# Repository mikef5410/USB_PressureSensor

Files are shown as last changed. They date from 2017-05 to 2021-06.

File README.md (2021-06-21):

## USB_Pressure_Sensor

USB measurement of Air pressure (compressor monitoring) The device also
includes an ambient air temperature, pressure, humidity monitor. As it happens
some of my work depends on a functioning air compressor, and ours is,
er... less than reliable. So, this device allows some of my automation to keep
an eye on the compressed air state, as well as air temperature, humidity and
pressure in the lab.

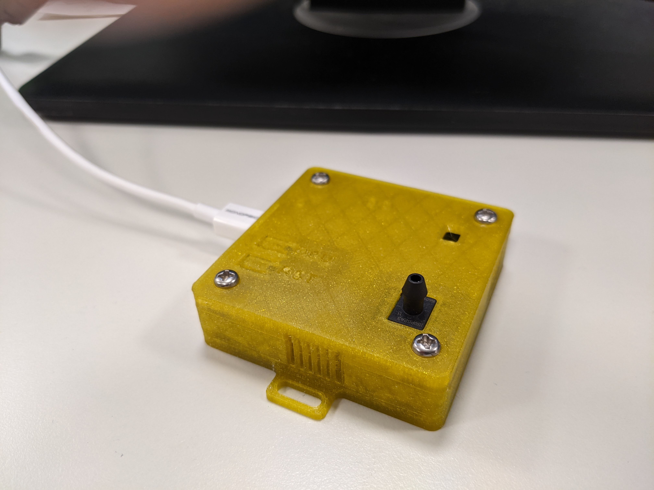
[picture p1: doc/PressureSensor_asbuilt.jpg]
USB Pressure Sensor as built


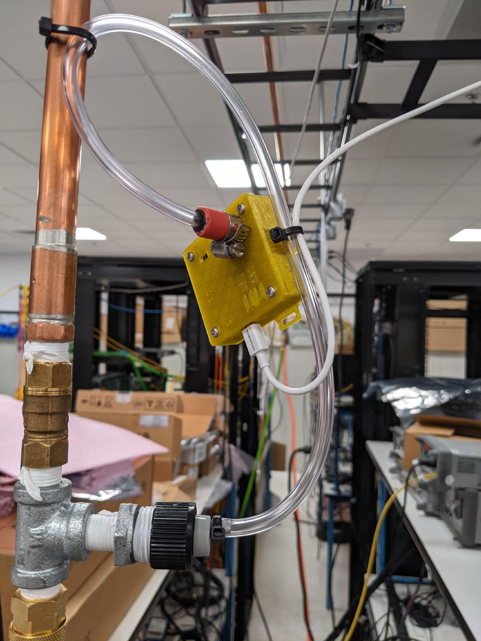
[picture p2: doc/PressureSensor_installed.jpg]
USB Pressure Sensor as installed


This project is an STM32F373 based USB gadget that measures air pressure in order to monitor compressor state.

The hardware design files are in Hardware, and a 3D-printable case is in Hardware/Mechanical.

This device uses FreeRTOS, and implements two interfaces on the bus...

1. A CDC-ACM interface with a simple commandline monitor
2. A simple COMMAND-RESPONSE packet interface on bulk endpoints 0x1/0x81. It's
this interface that the perl code in perl/ and perl/test talks to. It's made to
be dead simple machine-machine.

The controller consults EEprom for USB identifying material, so one board and
software load can fit many uses. perl/test/AttenSwitchTool can be used to modify the eeprom.

After cloning, run the bootstrap script to get the required submodules.

The 32F373 unfortunately needs an external 1500Ω pullup on USP_P to 3.3V which needs to be butched onto the board. It may be better to butch this to a GPIO output, but for now my board is using +3.3V.

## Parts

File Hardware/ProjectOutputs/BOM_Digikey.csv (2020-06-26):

Item | Supplier | SupplierPN | Manufacturer | ManufacturerPN | Quantity | Designator | Value | Description | Footprint
1 | Digi-Key
2 | Digi-Key |  | TDK | C1608X6S1A475K | 3 | C1, C7, C16 | 4.7uF | CAP 4.7uF +/-10% 10V X6S 0603 | CAP0603
3 | Digi-Key |  | TDK | C1005X5R1A105K | 2 | C2, C20 | 1uF | CAP 1uF +/-10% 10V X5R 0402 | CAP0402
4 | Digi-Key |  | TDK | C1005X7R1E104K | 6 | C3, C4, C5, C6, C12, C19 | 0.1uF | CAP 0.1uF +/-10% 25V X7R 0402 | CAP0402
5 | Digi-Key |  | TDK | C1608X7R1E105K | 3 | C8, C10, C13 | 1uF | CAP 1uF +/-10% 25V X7R 0603 | CAP0603
6 | Digi-Key |  | TDK | C1005X6S1H103M | 4 | C9, C11, C14, C18 | 0.01uF | CAP 0.01uF +/-20% 50V X6S 0402 | CAP0402
7 | Digi-Key |  | TDK | C1005C0G1H300J | 2 | C15, C17 | 30pF | CAP 30pF +/-5% 50V C0G 0402 | CAP0402
8 | Digi-Key | 568-4140-1-ND | NXP Semiconductors | PRTR5V0U2X | 1 | D1 |  | Diode Array, ESD Protection 1pF USB2.0 SOT143 | SOT190P230X110-4N
9 | Digi-Key | 754-1121-1-ND | Kingbright | APT1608SGC | 1 | D2 |  | LED 1.6X0.8MM 568NM GRN CLR SMD | KINGBRIGHT_LED
10 | Digi-Key | 754-1123-1-ND | Kingbright | APT1608SURCK | 2 | D3, D4 |  | LED 1.6X0.8MM 630NM RED CLR SMD | KINGBRIGHT_LED
11 | Digi-Key | 609-4616-1-ND | FCI | 10118193-0001LF | 1 | J1 |  | Connector Receptacle USB - micro B 2.0 5 Position Surface Mount, Right Angle, Horizontal | FCI_10118193
12 | Digi-Key | 445-1552-1-ND | MMZ1608Y102B | MMZ1608Y102B | 4 | L1, L2, L3, L4 |  | Ferrite, 1000oh, 400mA, 0603 | INDC1608X06N
13 | Digi-Key | P.10AKCT-ND | Panasonic | ERJ-2BSFR10X | 1 | R1 | 0.1 | RES .1 OHM 1/6W 1% 0402 SMD | RES0402
14 | Digi-Key | 541-10.0KLCT-ND | Vishay | CRCW040210K0FKED | 5 | R2, R7, R8, R11, R12 | 10.0K | Resistor SMT 0402 10.0K 1% ohm | RES0402
15 | Digi-Key | 541-0.0JCT-ND | Vishay | CRCW04020000Z0ED | 2 | R3, R13 | 0 | Resistor SMT 0402 0 1% ohm | RES0402
16 | Digi-Key | 541-100KLCT-ND | Vishay | CRCW0402100KFKED | 1 | R4 | 100K | Resistor SMT 0402 100K 1% ohm | RES0402
17 | Digi-Key | 541-100LCT-ND | Vishay | CRCW0402100RFKED | 4 | R5, R6, R9, R10 | 100 | Resistor SMT 0402 100 1% ohm | RES0402
18 | Digi-Key | CKN10384CT-ND | C&K Components | RS-282G05A3-SM RT | 2 | S1, S2 |  | SWITCH TACTILE SPST-NO 0.05A 12V 6x3.5MM | PTS635
19 | Digi-Key | 296-18476-1-ND | Texas Instruments | LP2985-33DBVR | 1 | U1 |  | Single Output Low Noise LDO, 150 mA, Fixed 3.3 V Output, 2.2 to 16 V Input, with Low IQ, 5-pin SOT-23 (DBV), -40 to 125 degC, Green (RoHS & no Sb/Br) | TI-DBV5_N
20 | Digi-Key | 93AA66AT-I/OTCT-ND | Microchip Technology | 93AA66AT-I/OT | 1 | U3 |  | IC EEPROM 4KBIT 2MHZ SOT23-6 | SOT-23-OT6_M
21 | Digi-Key | 497-13251-ND | ST Micro | STM32F373CCT6 | 1 | U4 |  | ARM Cortex-M4 32-bit MCU, 256 KB Flash, 32 KB Internal RAM, 36 I/Os, 48-pin LQFP, -40 to 85 degC, Tray | STM-LQFP48_N
22 | Digi-Key | 223-1701-1-ND | TE Connectivity | MS860702BA01-50 | 1 | X1 |  | Humidity, Pressure, Temperature Sensor I2C Output | TETempHumidityPressSens
23 | Digi-Key | 480-5413-ND | Honeywell | SSCDANN150PG2A3 | 1 | X2 |  | SENSOR PRES 150PSI GAUG 3.3V DIP I2C | HoneywellPsenseDIP
24 | Digi-Key | CTX732CT-ND | CTS-Frequency Controls | 403C11E16M00000 | 1 | Y1 |  | CRYSTAL 16.0MHZ 20PF,80ohm PARALLEL SMD +/-10PPM | CRYSTAL_SMD_3.2x2.5

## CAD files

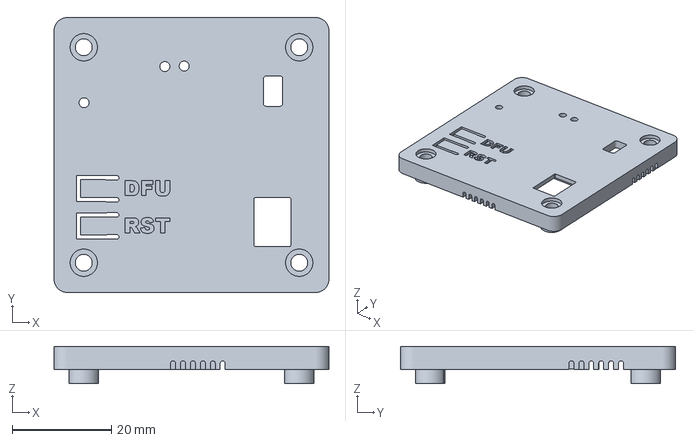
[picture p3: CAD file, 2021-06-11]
Hardware/Mechanical/PressureSensorEnclosure-LidLidBody.amf
55.4 x 55.4 x 7.50 mm

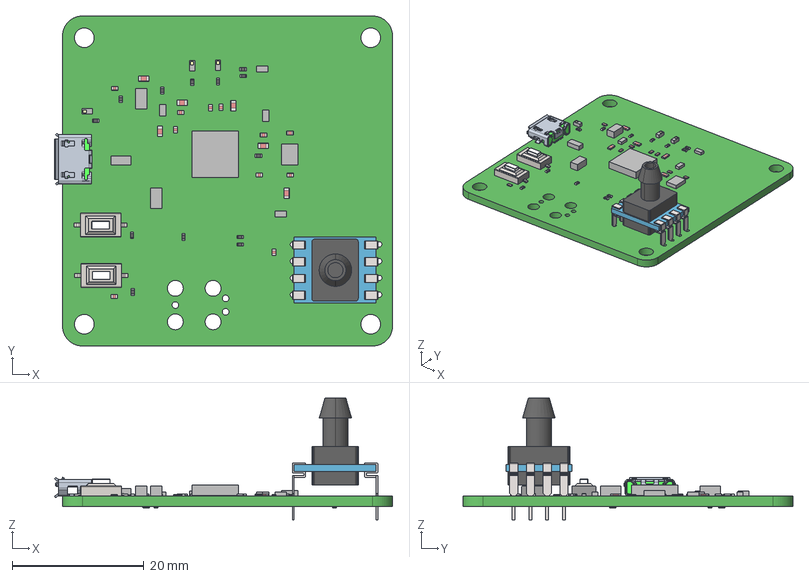
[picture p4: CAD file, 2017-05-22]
Hardware/ProjectOutputs/PressureSensor.step
51.2 x 50.0 x 18.4 mm
Board
Extruded x 15
User_Library-SSCDANT_Cono
User_Library-SSCDANT_Extruded x 8
User_Library-SSCDANT_Extruded_2 x 4
User_Library-SSCDANT_Extruded_3 x 4
User_Library-SSCDANT_Extruded_4
User_Library-SSCDANT_Extruded_5
User_Library-SSCDANT_Cylinder
Tactile_SMD_3x6x2.5mm x 2
RES0402 x 13
10118193-0001lfc
CAP0402 x 14
CAP0603 x 6

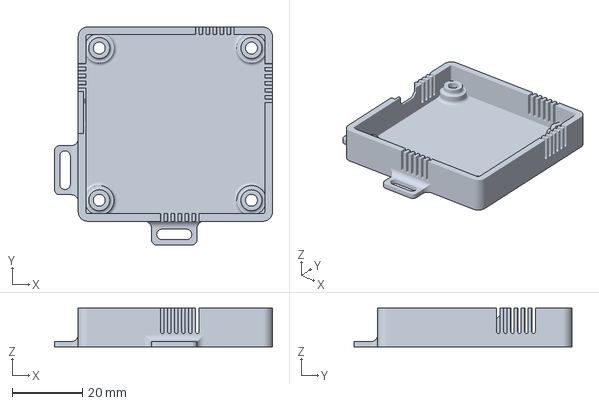
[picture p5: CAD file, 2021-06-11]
Hardware/Mechanical/PressureSensorEnclosure-BaseBaseBody.amf
62.2 x 62.2 x 11.0 mm

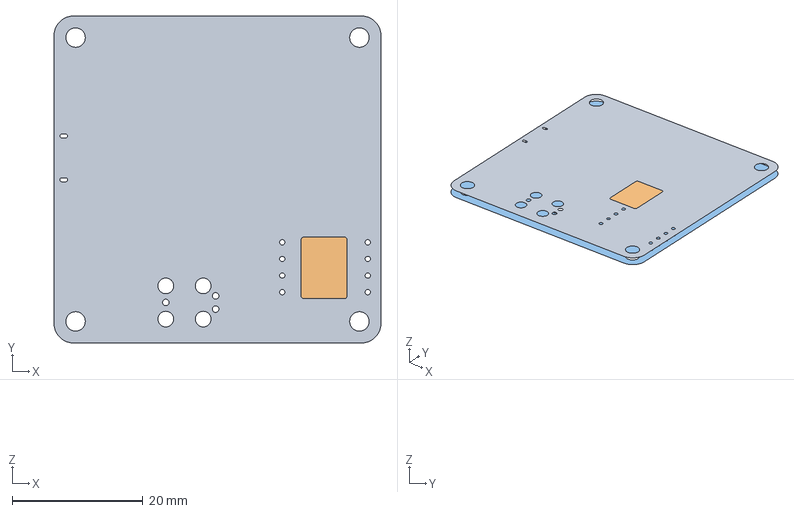
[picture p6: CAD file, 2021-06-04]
Hardware/Mechanical/PressureSensorEnclosure.FCStd
50.0 x 50.0 x 9.07 mm
Binder(PCB)
Binder002(PCB)...
Binder004(PCB)

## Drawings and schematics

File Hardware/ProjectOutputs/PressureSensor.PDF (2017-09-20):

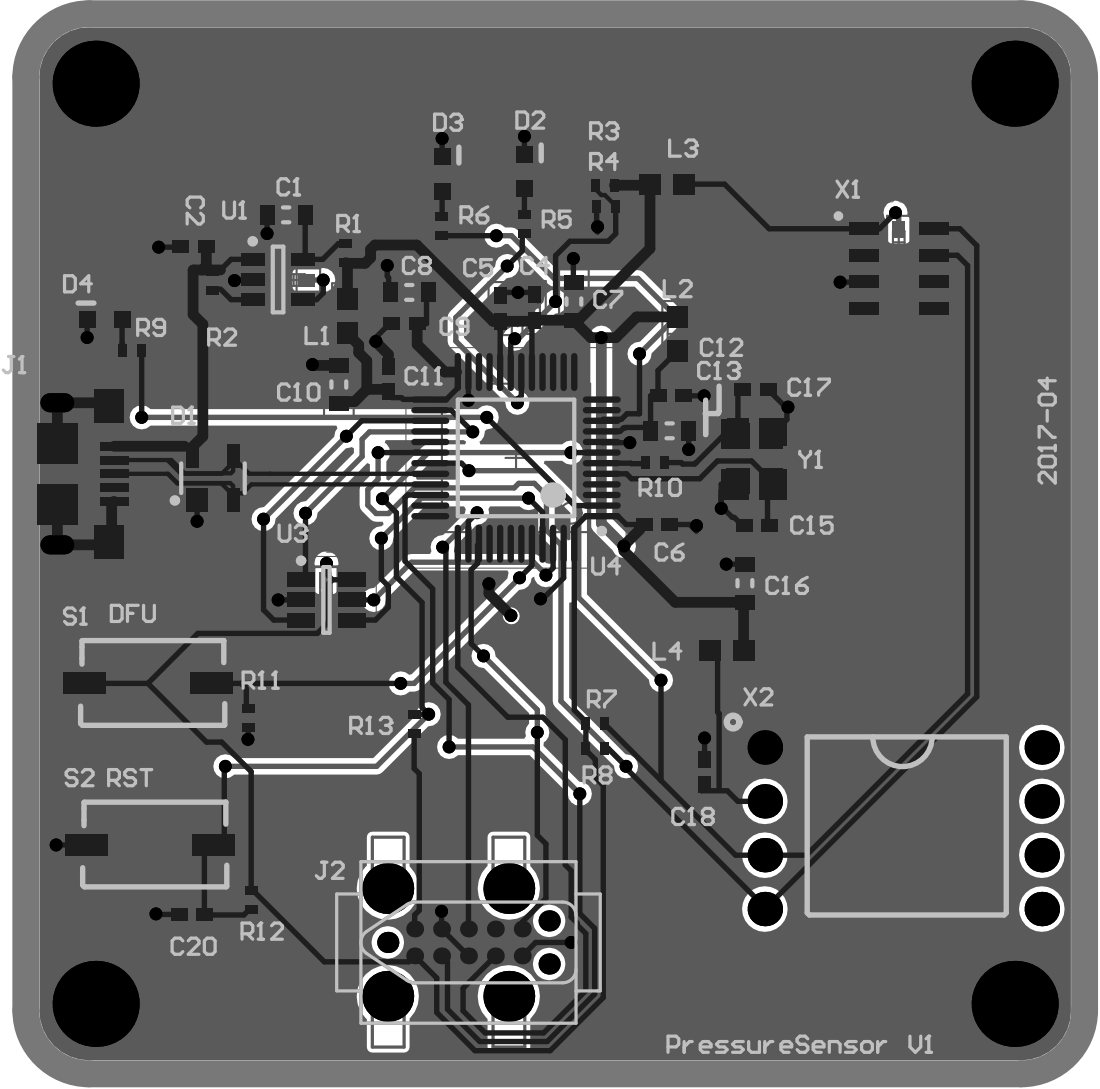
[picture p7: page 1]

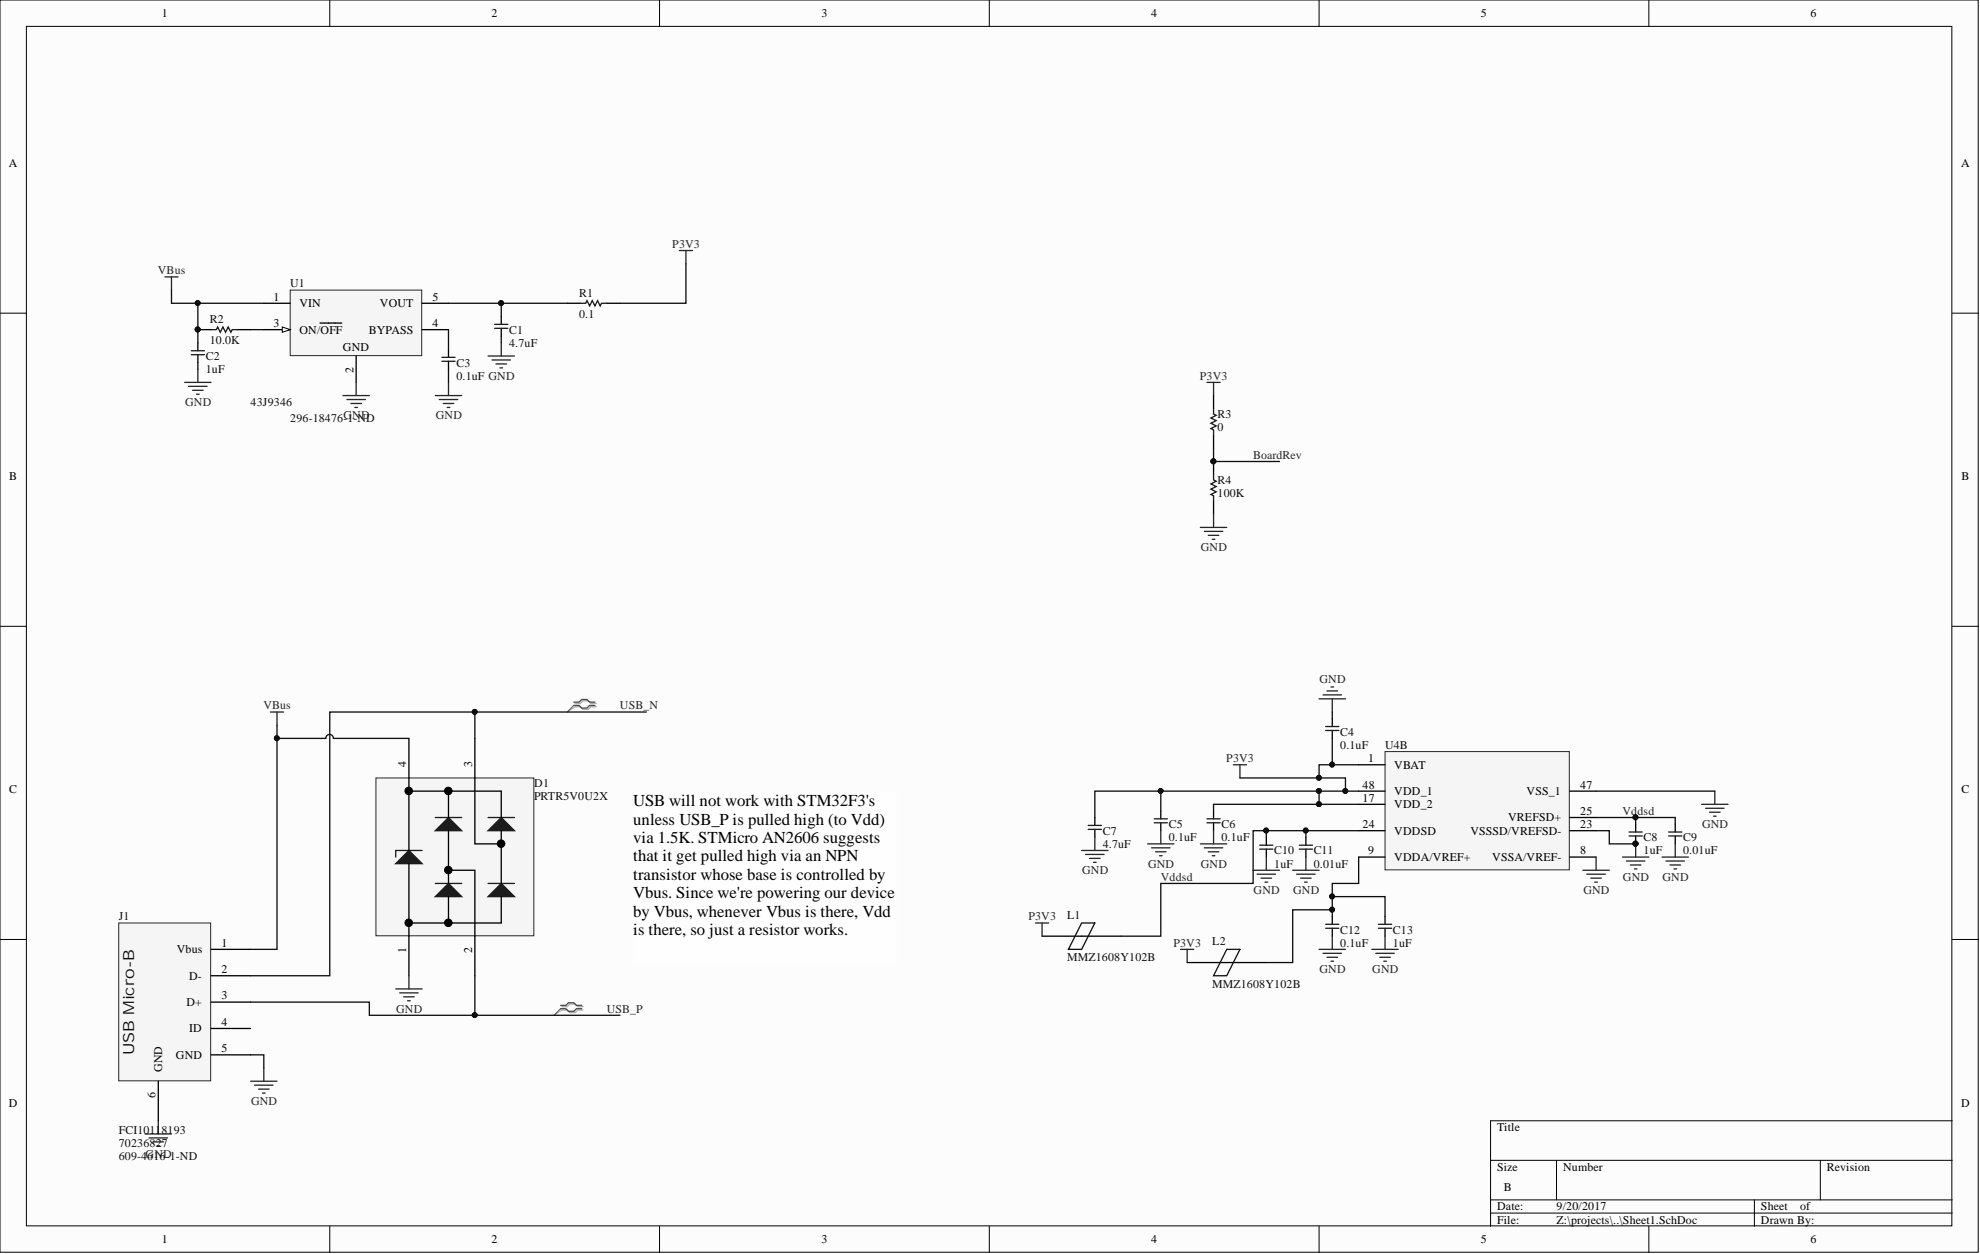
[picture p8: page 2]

USB will not work with STM32F3's
unless USB_P is pulled high (to Vdd)
via 1.5K. STMicro AN2606 suggests
that it get pulled high via an NPN
transistor whose base is controlled by
Vbus. Since we're powering our device
by Vbus, whenever Vbus is there, Vdd
is there, so just a resistor works.

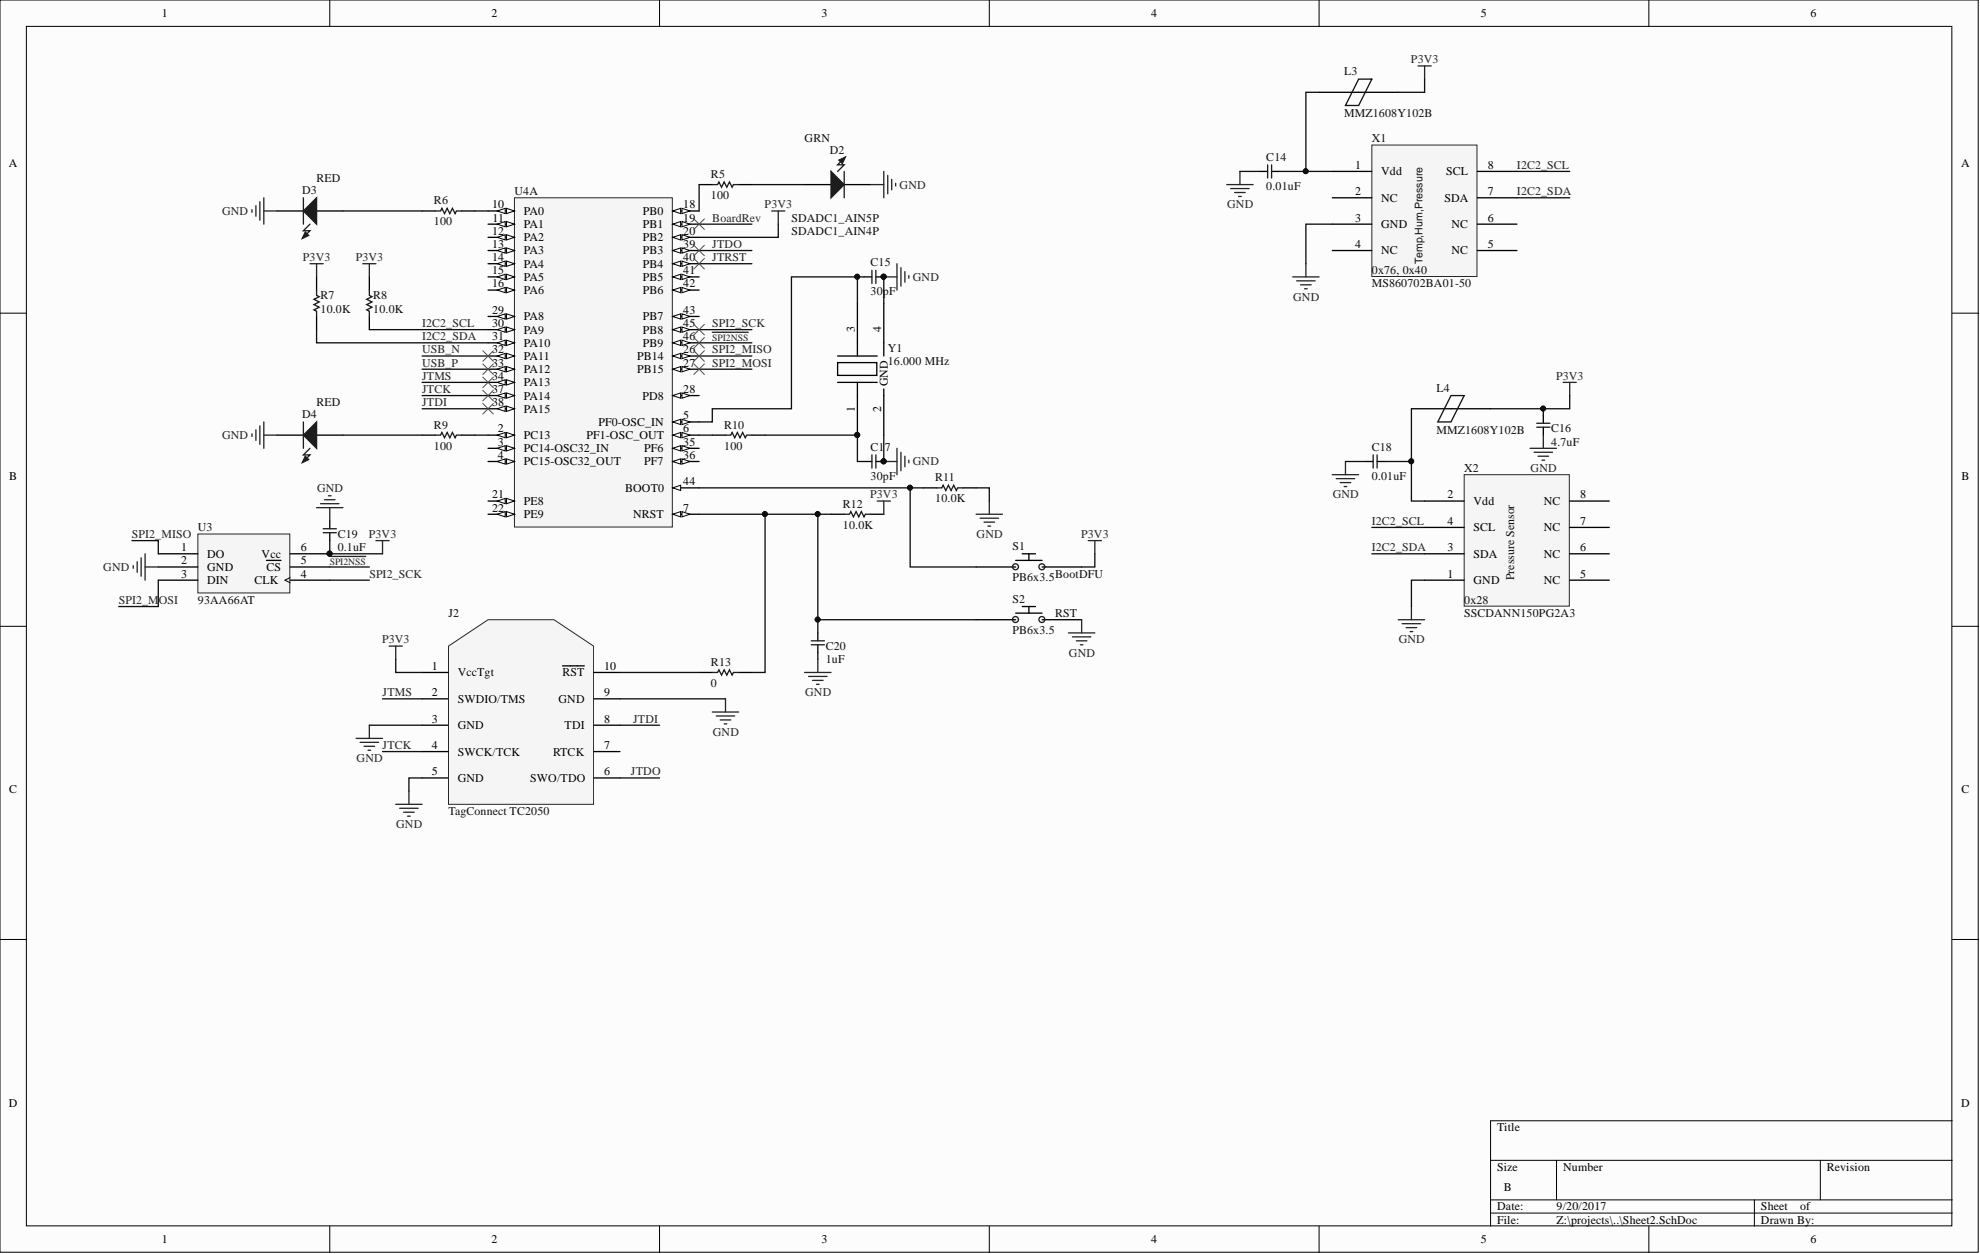
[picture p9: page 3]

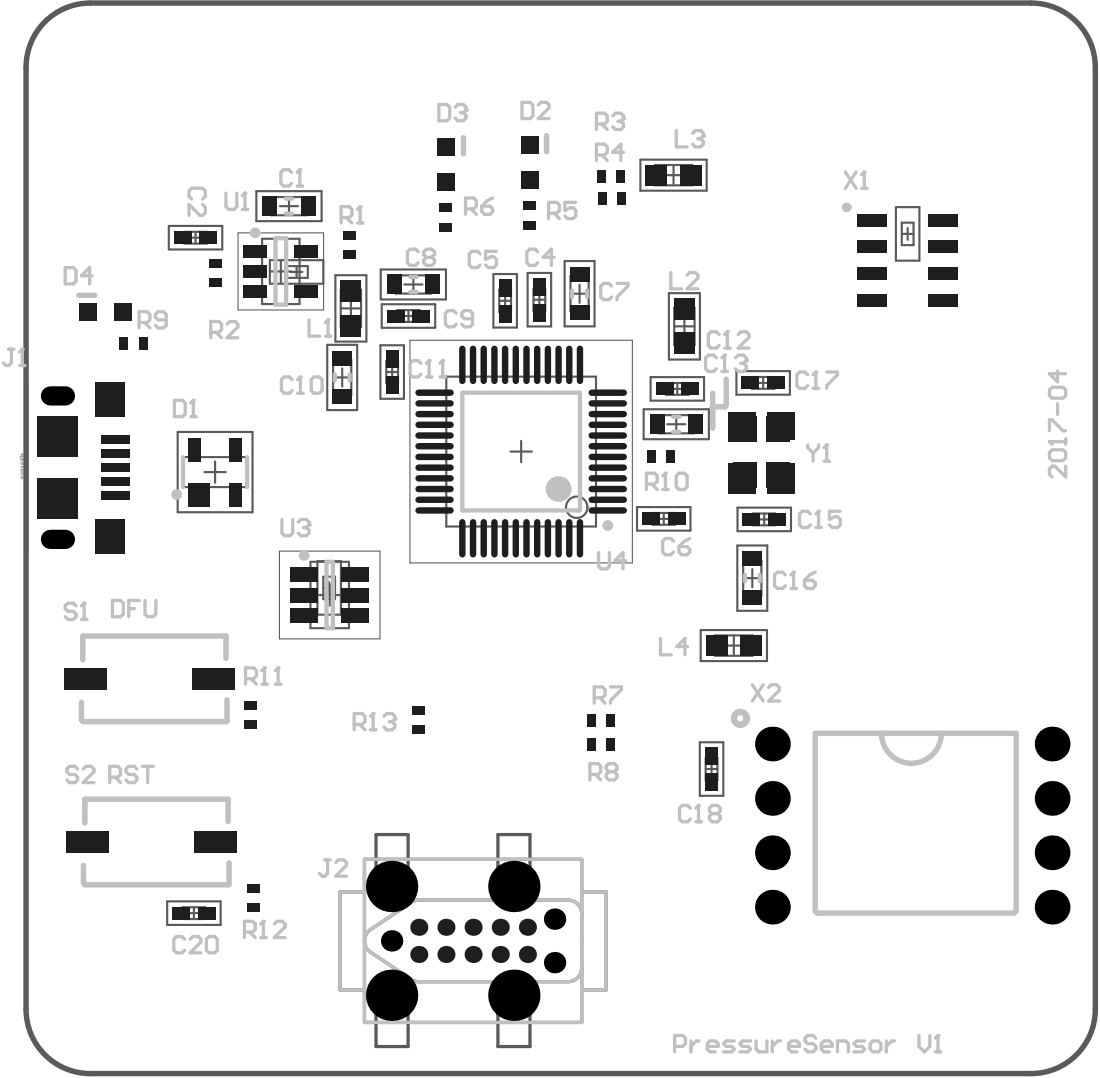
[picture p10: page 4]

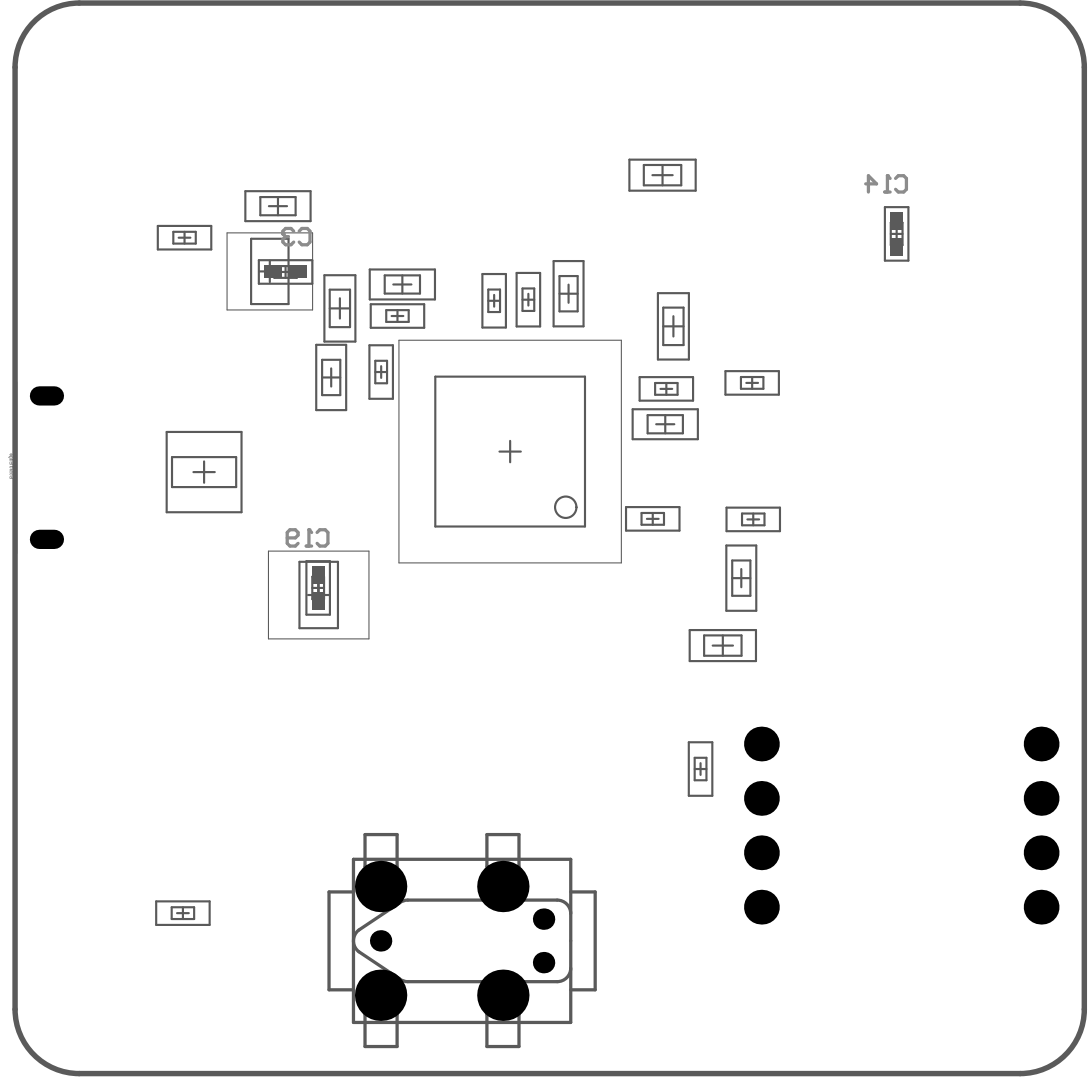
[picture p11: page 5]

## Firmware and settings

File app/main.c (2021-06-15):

#define GLOBAL_OSandPlatform
#include "OSandPlatform.h"

#include "debug_shell.h"
#include "instr_task.h"
#include "ms8607.h"

xTaskHandle *xLED1TaskHandle;
xTaskHandle *xStackTaskHandle;
xTaskHandle *xUSBCDCACMTaskHandle;
xTaskHandle *xDebugShellTaskHandle;
xTaskHandle *xInstrumentTaskHandle;

extern portTASK_FUNCTION(vUSBCDCACMTask, pvParameters); //in cdcacm.c
extern portTASK_FUNCTION(vStackTask, pvParamaters);
extern portTASK_FUNCTION(vInstrumentTask, pvParameters);
static portTASK_FUNCTION(vLEDTask1, pvParameters)
{
  (void)(pvParameters);//unused params

  while(1) {
    if (USBConfigured) {
      redOn(0);
      greenOn(1);
      delayms(50);
      greenOn(0);
      delayms(100);
      greenOn(1);
      delayms(50);
      greenOn(0);
      delayms(800);
    } else {
      redOn(1);
      delayms(100);
      greenOn(1);
      delayms(100);
      greenOn(0);
      usbLEDon(0);
      taskYIELD();
    }
  }
}



int main(void)
{
  portBASE_TYPE qStatus = pdPASS;   // = 1, this, and pdFAIL = 0, are in projdefs.h

  setupClocks();
  
  // Setup GPIOs
  setupGPIOs();


  redOn(1); greenOn(1); usbLEDon(1);
  Delay(0x1FFFFF);
  redOn(0); greenOn(0); usbLEDon(0);

  init_hiresTimer();
  setupTimers(); //HV turn-off timer
  
  //Fixup NVIC for FreeRTOS ...
  setupNVIC();

  setupI2C2();

  ms8607_init();
  if (ms8607_is_connected()) {
    ms8607_reset();
    ms8607_set_humidity_resolution(ms8607_humidity_resolution_11b);
    ms8607_set_pressure_resolution(ms8607_pressure_resolution_osr_8192);
    ms8607_disable_heater();
  }
  // Create tasks
  // remember, stack size is in 32-bit words and is allocated from the heap ...
  qStatus = xTaskCreate(vUSBCDCACMTask, "USB Serial Task", 64, NULL, (tskIDLE_PRIORITY + 1UL),
                        (xTaskHandle *) &xUSBCDCACMTaskHandle);

  qStatus = xTaskCreate(vLEDTask1, "LED Task 1", 64, NULL, (tskIDLE_PRIORITY + 1UL),
                        (xTaskHandle *) &xLED1TaskHandle);

  qStatus = xTaskCreate(vDebugShell, "Debug shell", 1200, NULL, (tskIDLE_PRIORITY + 1UL),
                        (xTaskHandle *) &xDebugShellTaskHandle);

  qStatus = xTaskCreate(vInstrumentTask, "Instrument task", 1500, NULL,  (tskIDLE_PRIORITY + 1UL),
                        (xTaskHandle *) &xInstrumentTaskHandle);
 
  (void) qStatus;

  // start the scheduler
  vTaskStartScheduler();

  /* Control should never come here */
  //DEBUGSTR("Scheduler Failure\n");
  while (1) {}
}
  



void vApplicationStackOverflowHook( xTaskHandle xTask __attribute__(( unused )), signed char *pcTaskName __attribute__(( unused )) )
{
  while (1) {
  }  
  return;
}

void vApplicationMallocFailedHook( void ) {
  while (1) {
  }  
  return;
}

//	vApplicationIdleHook() ...
// 
//  will only be called if configUSE_IDLE_HOOK is set to 1 in FreeRTOSConfig.h.
//  It will be called on each iteration of the idle task.
//
//	It is essential that code added to this hook function never attempts
//	to block in any way (for example, call xQueueReceive() with a block time
//	specified, or call vTaskDelay()).  If the application makes use of the
//	vTaskDelete() API function (as this demo application does) then it is also
//	important that vApplicationIdleHook() is permitted to return to its calling
//	function, because it is the responsibility of the idle task to clean up
//	memory allocated by the kernel to any task that has since been deleted.
//
void vApplicationIdleHook( void ) {
  // jjones:  I have configured to use the IdleHook, but don't
  //          really have anything for it do do... yet.
  //          The default behavior is just to surrender to the tick ...
  __WFI();
  // What is shown below is from an LWIP and USB-CDC demo, where the idle task
  // lazy-dumps characters out the USB port.  I include it as a tutorial on
  // using the TickCount (or some other higher-res timer) to  prevent the
  // idle task from churning, or sending any faster than necessary.

  //  static portTickType xLastTx = 0;
  //  char cTxByte;
  //  
  //  /* The idle hook simply sends a string of characters to the USB port.
  //  	 The characters will be buffered and sent once the port is connected. */
  //  if( ( xTaskGetTickCount() - xLastTx ) > mainUSB_TX_FREQUENCY ) {
  //  	xLastTx = xTaskGetTickCount();
  //  	for( cTxByte = mainFIRST_TX_CHAR; cTxByte <= mainLAST_TX_CHAR; cTxByte++ ) {
  //  	  vUSBSendByte( cTxByte );
  //  	}		
  //  }
} // end vApplicationIdleHook


// FreeRTOS application tick hook 
void vApplicationTickHook(void)
{}

void _exit(int status __attribute__(( unused )) )
{
  //TRIG_HARDFAULT;
  while (1) ;
}

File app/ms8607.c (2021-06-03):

/**
 * \file ms8607.c
 *
 * \brief MS8607 Temperature sensor driver source file
 *
 * Copyright (c) 2016 Measurement Specialties. All rights reserved.
 *
 * For details on programming, refer to ms8607 datasheet :
 * http://www.meas-spec.com/downloads/MS8607D.pdf
 *
 */
#include "OSandPlatform.h"

#include "ms8607.h"

/**
 * The header "i2c.h" has to be implemented for your own platform to 
 * conform the following protocol :
 *
 * enum i2c_transfer_direction {
 * 	I2C_TRANSFER_WRITE = 0,
 * 	I2C_TRANSFER_READ  = 1,
 * };
 * 
 * enum status_code {
 * 	STATUS_OK           = 0x00,
 * 	STATUS_ERR_OVERFLOW	= 0x01,
 *		STATUS_ERR_TIMEOUT  = 0x02,
 * };
 * 
 * struct i2c_master_packet {
 * 	// Address to slave device
 * 	uint16_t address;
 * 	// Length of data array
 * 	uint16_t data_length;
 * 	// Data array containing all data to be transferred
 * 	uint8_t *data;
 * };
 * 
 * void i2c_master_init(void);
 * enum status_code i2c_master_read_packet_wait(struct i2c_master_packet *const packet);
 * enum status_code i2c_master_write_packet_wait(struct i2c_master_packet *const packet);
 * enum status_code i2c_master_write_packet_wait_no_stop(struct i2c_master_packet *const packet);
 */

#ifdef __cplusplus
extern "C" {
#endif

  // HSENSOR device address
#define HSENSOR_ADDR					0x40	//0b1000000

  // HSENSOR device commands
#define HSENSOR_RESET_COMMAND				0xFE
#define HSENSOR_READ_HUMIDITY_W_HOLD_COMMAND		0xE5
#define HSENSOR_READ_HUMIDITY_WO_HOLD_COMMAND		0xF5
#define HSENSOR_READ_SERIAL_FIRST_8BYTES_COMMAND	0xFA0F
#define HSENSOR_READ_SERIAL_LAST_6BYTES_COMMAND		0xFCC9
#define HSENSOR_WRITE_USER_REG_COMMAND			0xE6
#define HSENSOR_READ_USER_REG_COMMAND			0xE7

  // Processing constants
#define HSENSOR_TEMPERATURE_COEFFICIENT			(float)(-0.15)
#define HSENSOR_CONSTANT_A				(float)(8.1332)
#define HSENSOR_CONSTANT_B				(float)(1762.39)
#define HSENSOR_CONSTANT_C				(float)(235.66)

  // Coefficients for temperature computation
#define TEMPERATURE_COEFF_MUL				(175.72)
#define TEMPERATURE_COEFF_ADD				(-46.85)

  // Coefficients for relative humidity computation
#define HUMIDITY_COEFF_MUL				(125)
#define HUMIDITY_COEFF_ADD				(-6)

  // Conversion timings
#define HSENSOR_CONVERSION_TIME_12b			20000
#define HSENSOR_CONVERSION_TIME_10b		        9000
#define HSENSOR_CONVERSION_TIME_8b			5000
#define HSENSOR_CONVERSION_TIME_11b			15000

#define HSENSOR_RESET_TIME				15	// ms value

  // HSENSOR User Register masks and bit position
#define HSENSOR_USER_REG_RESOLUTION_MASK		0x81
#define HSENSOR_USER_REG_END_OF_BATTERY_MASK		0x40
#define HSENSOR_USER_REG_ENABLE_ONCHIP_HEATER_MASK	0x4
#define HSENSOR_USER_REG_DISABLE_OTP_RELOAD_MASK	0x2
#define HSENSOR_USER_REG_RESERVED_MASK		(~(		HSENSOR_USER_REG_RESOLUTION_MASK \
                                                                |	HSENSOR_USER_REG_END_OF_BATTERY_MASK \
                                                                |	HSENSOR_USER_REG_ENABLE_ONCHIP_HEATER_MASK \
                                                                |	HSENSOR_USER_REG_DISABLE_OTP_RELOAD_MASK ))

  // HTU User Register values
  // Resolution
#define HSENSOR_USER_REG_RESOLUTION_12b			0x00
#define HSENSOR_USER_REG_RESOLUTION_11b			0x81
#define HSENSOR_USER_REG_RESOLUTION_10b			0x80
#define HSENSOR_USER_REG_RESOLUTION_8b			0x01

  // End of battery status
#define HSENSOR_USER_REG_END_OF_BATTERY_VDD_ABOVE_2_25V	0x00
#define HSENSOR_USER_REG_END_OF_BATTERY_VDD_BELOW_2_25V	0x40
  // Enable on chip heater
#define HSENSOR_USER_REG_ONCHIP_HEATER_ENABLE		0x04
#define HSENSOR_USER_REG_OTP_RELOAD_DISABLE		0x02

  // PSENSOR device address
#define PSENSOR_ADDR					0x76	//0b1110110

  // PSENSOR device commands
#define PSENSOR_RESET_COMMAND				0x1E
#define PSENSOR_START_PRESSURE_ADC_CONVERSION		0x40
#define PSENSOR_START_TEMPERATURE_ADC_CONVERSION	0x50
#define PSENSOR_READ_ADC				0x00

#define PSENSOR_CONVERSION_OSR_MASK			0x0F

#define PSENSOR_CONVERSION_TIME_OSR_256			1000   // usec
#define PSENSOR_CONVERSION_TIME_OSR_512			2000
#define PSENSOR_CONVERSION_TIME_OSR_1024		3000
#define PSENSOR_CONVERSION_TIME_OSR_2048		5000
#define PSENSOR_CONVERSION_TIME_OSR_4096		9000
#define PSENSOR_CONVERSION_TIME_OSR_8192		18000

  // PSENSOR commands
#define PROM_ADDRESS_READ_ADDRESS_0			0xA0
#define PROM_ADDRESS_READ_ADDRESS_1			0xA2
#define PROM_ADDRESS_READ_ADDRESS_2			0xA4
#define PROM_ADDRESS_READ_ADDRESS_3			0xA6
#define PROM_ADDRESS_READ_ADDRESS_4			0xA8
#define PROM_ADDRESS_READ_ADDRESS_5			0xAA
#define PROM_ADDRESS_READ_ADDRESS_6			0xAC
#define PROM_ADDRESS_READ_ADDRESS_7			0xAE

  // Coefficients indexes for temperature and pressure computation
#define CRC_INDEX					0
#define PRESSURE_SENSITIVITY_INDEX			1
#define PRESSURE_OFFSET_INDEX				2
#define TEMP_COEFF_OF_PRESSURE_SENSITIVITY_INDEX	3
#define TEMP_COEFF_OF_PRESSURE_OFFSET_INDEX		4
#define REFERENCE_TEMPERATURE_INDEX			5
#define TEMP_COEFF_OF_TEMPERATURE_INDEX			6
#define COEFFICIENT_NUMBERS				7
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

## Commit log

2017-05-22 Initial. Copied from usbAttenController@75c830f3eb9839707b81e032300b0444e7532690 and added Hardware files.
    [BOM_Digikey.csv, BOM_Digikey.csv.xls, BOM_PressureSensor.xls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]
2017-05-24 Switch over to STM32F373 ... not done yet
2017-09-20 Update hardware
    [BOM_PressureSensor.xls, Bill of Materials-PressureSensor.csv, PressureSensor.step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]
2020-06-26 Add note of processor
    [BOM_Digikey.csv]
2021-06-01 Fix spi to EEProm
    [eeprom9366.c]
2021-06-01 Double spi clock to 1.125MHz
2021-06-01 Add temp/hum sensor and pressure sensor drivers
2021-06-03 Pressure sensor driver implemented.
2021-06-03 Add instrument commands for ambient and air line air pressure.
2021-06-04 Add mechanicals
    [PressureSensorEnclosure.FCStd]
2021-06-11 Fix minor interference, Screw head penetration
    [PressureSensorEnclosure-BaseBaseBody.amf, PressureSensorEnclosure-BottomBottomBody.amf, PressureSensorEnclosure-LidLidBody.amf]
2021-06-13 Unify command enums with Attenuator/Switch tool. Fix temp, pressure readings.
2021-06-15 Fix hang. Interrupts were apparently coming in during usb_poll() call.
    [cdcacm.c, main.c, ms8607.c]
2021-06-16 Turn off SOF interrupts. I don't use them.
2021-06-17 Add pressure daemon and cgi
